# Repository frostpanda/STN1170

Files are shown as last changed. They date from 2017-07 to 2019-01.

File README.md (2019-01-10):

<h2><b>Prototype of common OBD diagnostic board </b></h2>

Device uses STN1170 chip in QFTP package, form ScanTool company and it is compatible with ELM327, based on information, which can be found in datasheet about this integrated circuit. 

Main assumption about this prototype to be a modular to lower the cost of the device, because only 3 samples can be acquired through ScanTool company, so prototype has two boards. One with STN1170 and necessary components and second one with transceivers, which are required for communication with proper protocols and OBD chip, but also contains wireless and wired communication. 

Wireless communication was planned RN4870 BLE module. But because of bad implementation (???) or module was broken I can not force him to work properly. In the end it lost MAC address and this is common for modules, based on IS187x Bluetooth LE ICs and the main reason for it was as Microchip support claim “Inappropriate module reset”, but I didn’t get answer for my question, when I asked about, how this module should be reset, to prevent such behavior in the future. Finally I decided for HM-13 module. Module is already implemented and I need to do more tweaking in revision 2 to push next revision. For now module is working on revision 1 prototype board.

Wired communication with PC uses CP2102N UART to Bridge ICs. His cost is lower than FTDI chips and has a lot possible ways to configure it, beginning from drivers, ending at ICs, but soldering it without hot air station is not easy task to do, but it can be done with some patience.

After success of 1st prototype (working!), second was made. On the 2nd prototype everything was moved to the one 2 layers PCB board, with dimension of 4cm x 6cm (I will try to make it even smaller!, but I am concern about EMC problem with it and this could require use 4 layer PCB). Some of components are on the bottom side of the board. 

Checked protocols:
- [x] High Speed CAN
- [x] Medium Speed CAN 
- [x] Single Wire CAN 
- [x] K-LINE
- [x] L-LINE
- [ ] VPW 
- [ ] PWM

Basic connection tested with:
- Fiat Punto MK2 1.2 8V (MultiEcuScan)
- Opel Vectra C 1.8 16V 122KM 
- Citroen DS4 
- Mazda 3 BK 1.6 105KM Z6 2008 (ForScan)

Gallery: https://imgur.com/a/UtiDV

Video: https://youtu.be/GFeOGx49xKc

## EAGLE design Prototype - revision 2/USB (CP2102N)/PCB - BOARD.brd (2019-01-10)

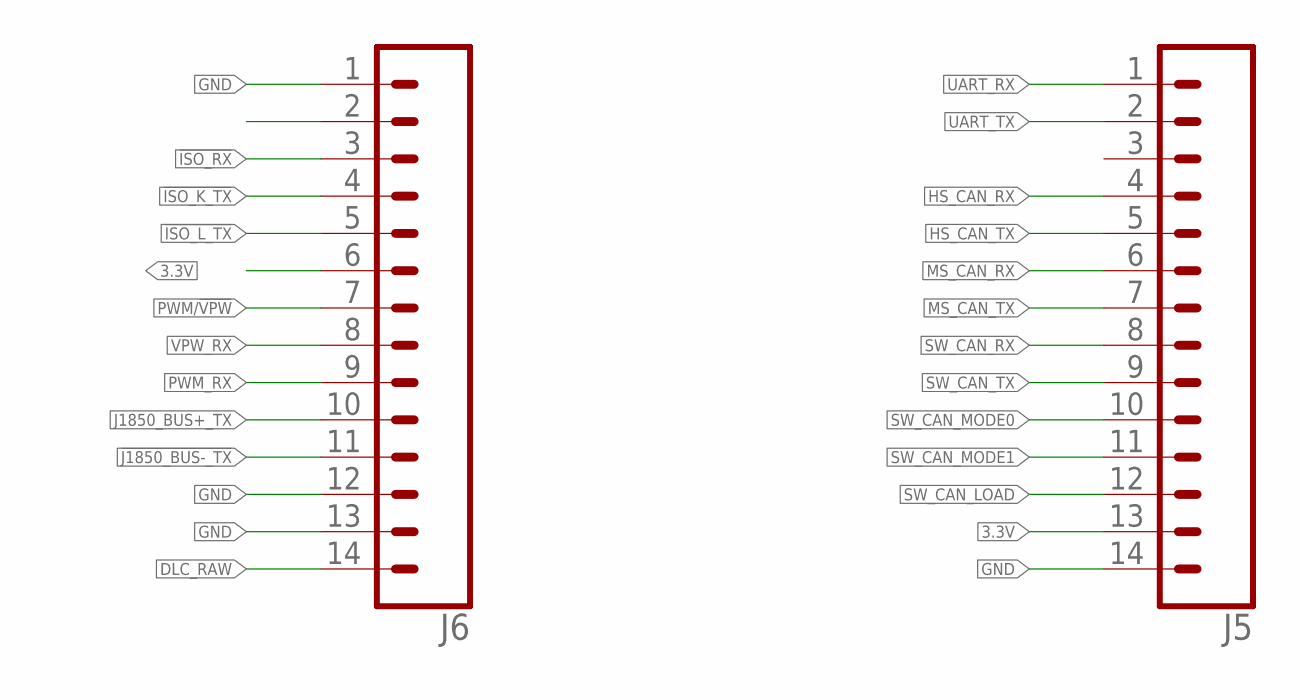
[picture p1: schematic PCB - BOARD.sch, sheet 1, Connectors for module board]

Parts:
J5, J6: CONN_14; 1X14

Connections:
3.3V: J5.13, J6.6; also elsewhere on the board
!ISO_K_TX: J6.4; also elsewhere on the board
!ISO_L_TX: J6.5; also elsewhere on the board
!ISO_RX: J6.3; also elsewhere on the board
!J1850_BUS-_TX: J6.11; also elsewhere on the board
DLC_RAW: J6.14; also elsewhere on the board
GND: J5.14, J6.1, J6.2, J6.12, J6.13; also elsewhere on the board
HS_CAN_RX: J5.4; also elsewhere on the board
HS_CAN_TX: J5.5; also elsewhere on the board
J1850_BUS+_TX: J6.10; also elsewhere on the board
MS_CAN_RX: J5.6; also elsewhere on the board
MS_CAN_TX: J5.7; also elsewhere on the board
PWM/!VPW: J6.7; also elsewhere on the board
PWM_RX: J6.9; also elsewhere on the board
SW_CAN_LOAD: J5.12; also elsewhere on the board
SW_CAN_MODE0: J5.10; also elsewhere on the board
SW_CAN_MODE1: J5.11; also elsewhere on the board
SW_CAN_RX: J5.8; also elsewhere on the board
SW_CAN_TX: J5.9; also elsewhere on the board
UART_RX: J5.1; also elsewhere on the board
UART_TX: J5.2; also elsewhere on the board
VPW_RX: J6.8; also elsewhere on the board

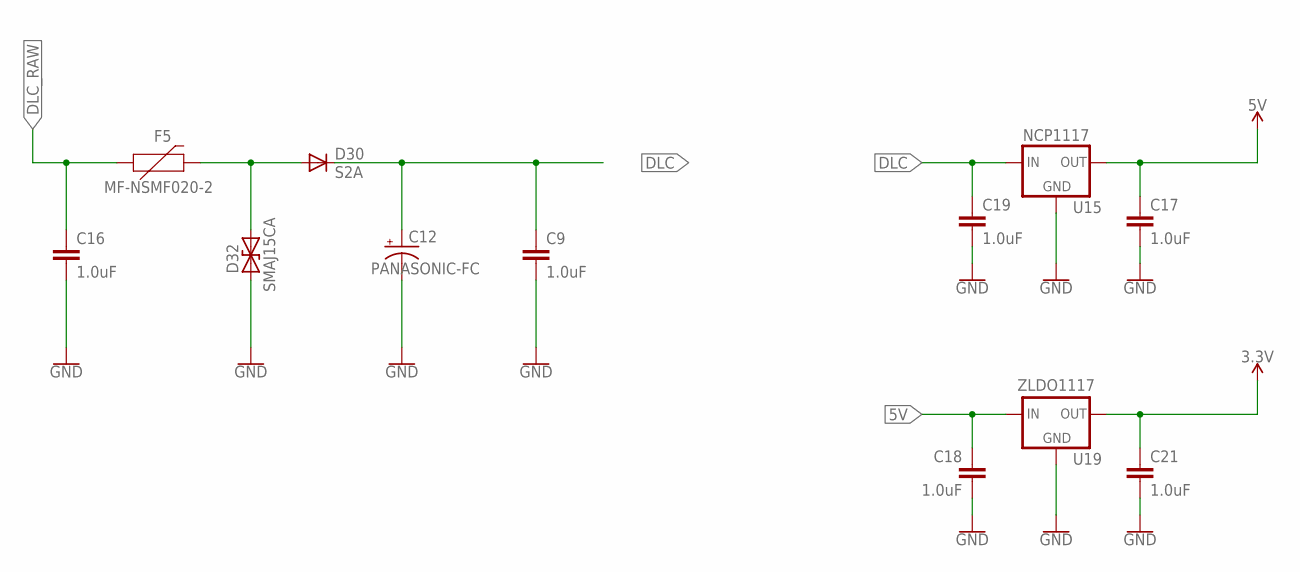
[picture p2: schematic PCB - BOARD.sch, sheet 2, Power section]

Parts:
C9, C16, C17, C18, C19, C21: 1.0uF; 0805
C12: PANASONIC-FC; 5X11
D30: S2A; DO214AA
D32: SMAJ15CA; DO214AC
F5: MF-NSMF020-2; 1206
U15: NCP1117; TO-252
U19: ZLDO1117; SOT223

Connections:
3.3V: C21.1, U19.2 (OUT), U19.4 (OUT); also elsewhere on the board
5V: C17.1, C18.1, U15.2 (OUT), U19.3 (IN); also elsewhere on the board
DLC: C9.1, C12.2 (+), C19.1, D30.C, U15.3 (IN); also elsewhere on the board
DLC_RAW: C16.1, F5.1; also elsewhere on the board
DLC_RAW2: D30.A, D32.C (2), F5.2
GND: C9.2, C12.1 (-), C16.2, C17.2, C18.2, C19.2, C21.2, D32.A (1), U15.1 (GND), U19.1 (GND); also elsewhere on the board

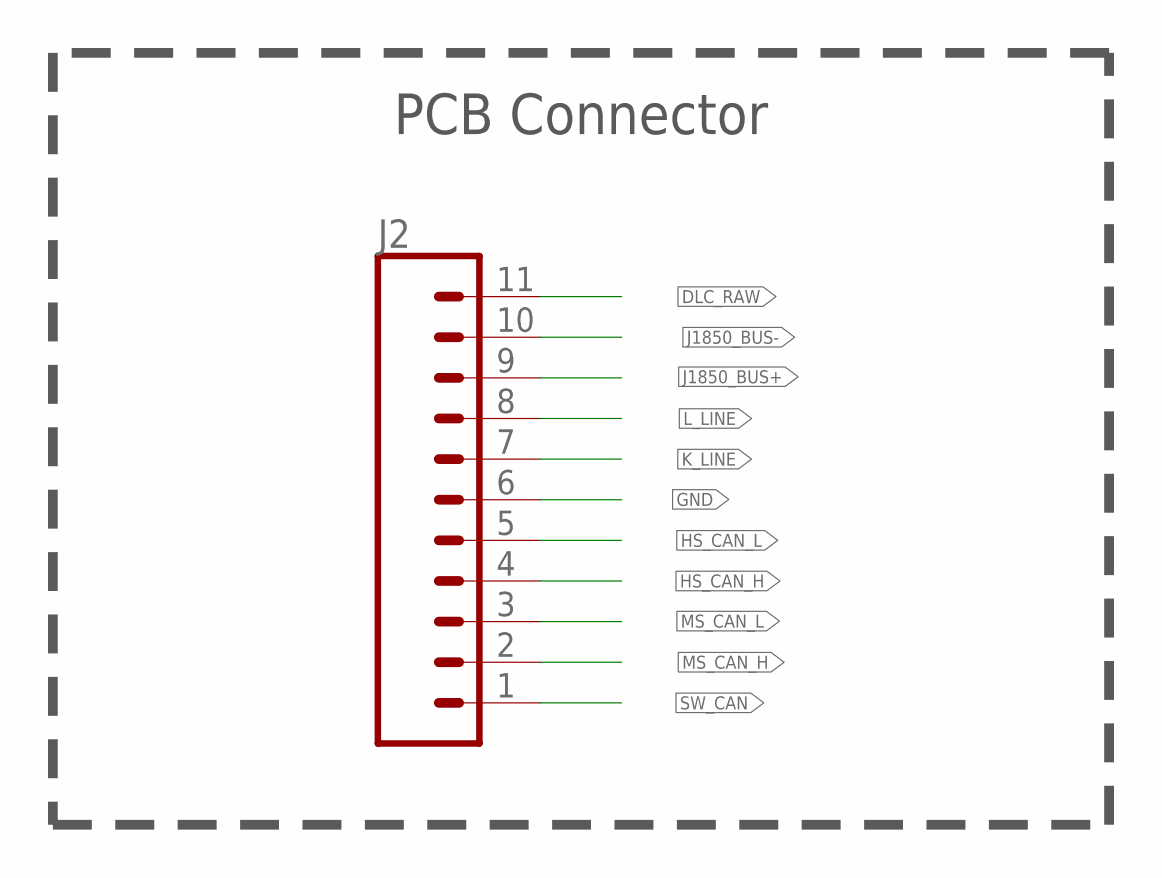
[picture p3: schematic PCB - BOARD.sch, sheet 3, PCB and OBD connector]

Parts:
J2: CONN_11; 1X11

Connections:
DLC_RAW: J2.11; also elsewhere on the board
GND: J2.6; also elsewhere on the board
HS_CAN_H: J2.4; also elsewhere on the board
HS_CAN_L: J2.5; also elsewhere on the board
J1850_BUS+: J2.9; also elsewhere on the board
J1850_BUS-: J2.10; also elsewhere on the board
K_LINE: J2.7; also elsewhere on the board
L_LINE: J2.8; also elsewhere on the board
MS_CAN_H: J2.2; also elsewhere on the board
MS_CAN_L: J2.3; also elsewhere on the board
SW_CAN: J2.1; also elsewhere on the board

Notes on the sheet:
PCB Connector

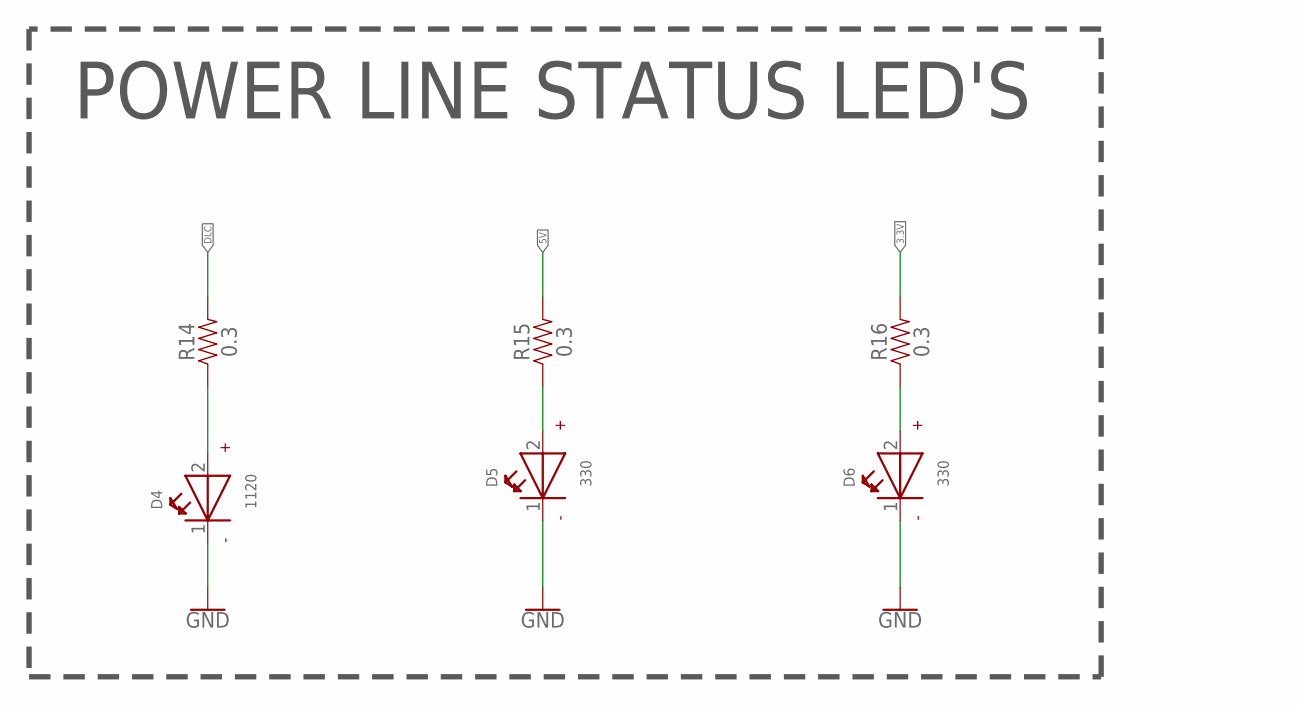
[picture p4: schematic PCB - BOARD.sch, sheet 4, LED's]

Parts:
D4: 1120; WL-SMCW_1206
D5, D6: 330; WL-SMCW_1206
R14, R15, R16: 0.3; 0805

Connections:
3.3V: R16.2; also elsewhere on the board
5V: R15.2; also elsewhere on the board
DLC: R14.2; also elsewhere on the board
GND: D4.1 (-), D5.1 (-), D6.1 (-); also elsewhere on the board
unnamed: D6.2 (+), R16.1
unnamed: D5.2 (+), R15.1
unnamed: D4.2 (+), R14.1

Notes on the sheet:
POWER LINE STATUS LED'S

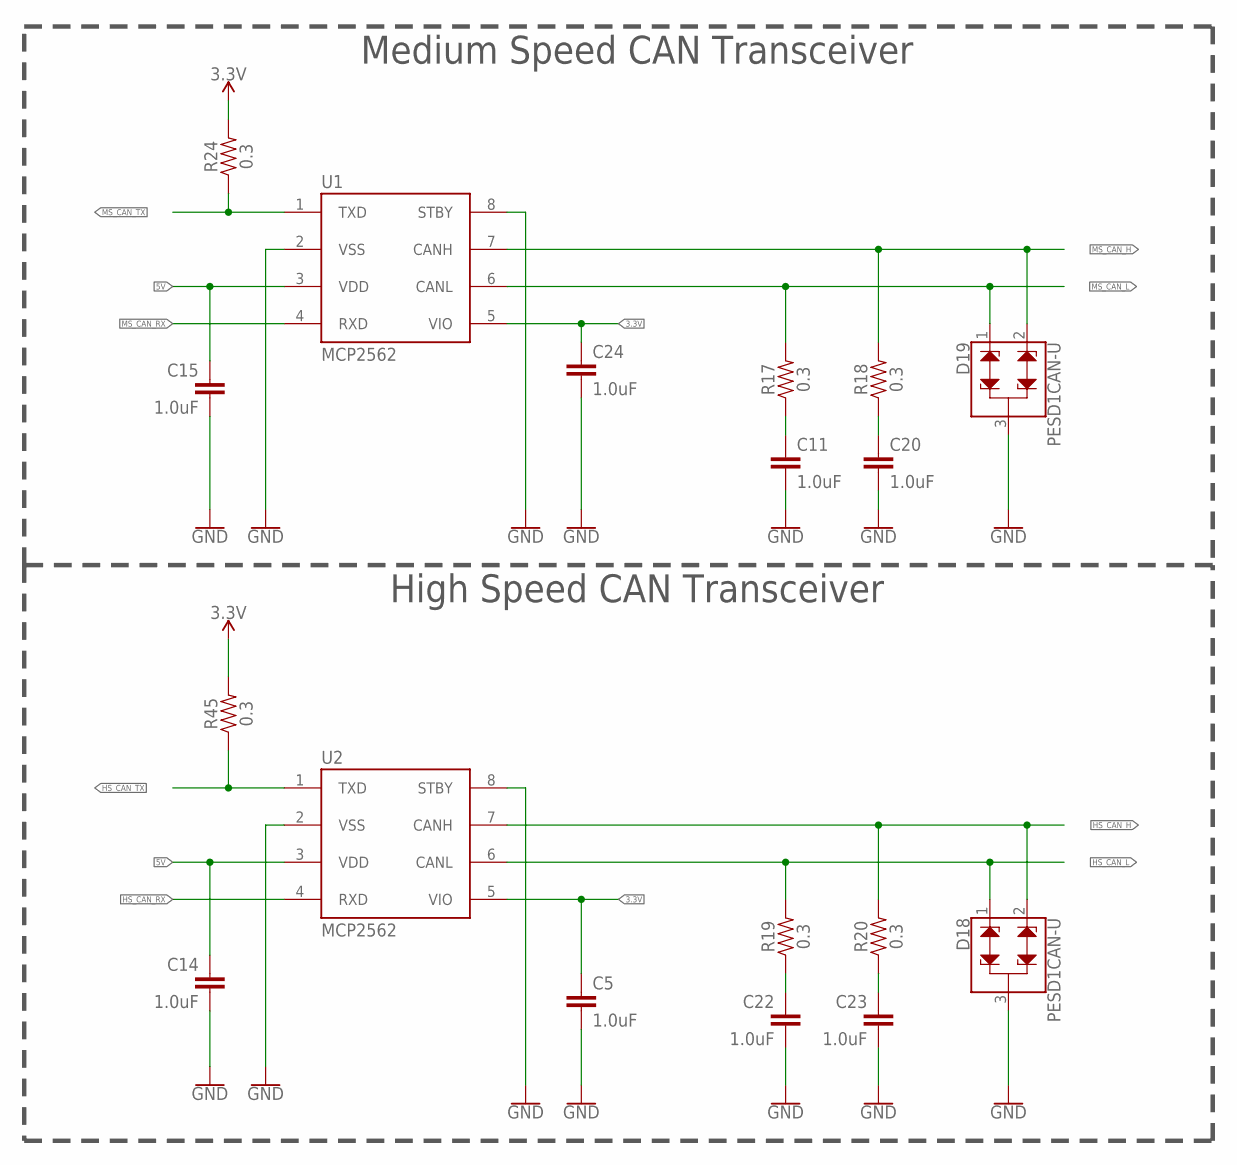
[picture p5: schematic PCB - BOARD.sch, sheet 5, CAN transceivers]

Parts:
C5, C11, C14, C15, C20, C22, C23, C24: 1.0uF; 0805
D18, D19: PESD1CAN-U; SOT323
R17, R18, R19, R20, R24, R45: 0.3; 0805
U1, U2: MCP2562; SOIC-8

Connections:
3.3V: C5.1, C24.1, R24.2, R45.2, U1.5 (VIO), U2.5 (VIO); also elsewhere on the board
5V: C14.1, C15.1, U1.3 (VDD), U2.3 (VDD); also elsewhere on the board
GND: C5.2, C11.2, C14.2, C15.2, C20.2, C22.2, C23.2, C24.2, D18.3, D19.3, U1.2 (VSS), U1.8 (STBY), U2.2 (VSS), U2.8 (STBY); also elsewhere on the board
HS_CAN_H: D18.2, R20.2, U2.7 (CANH); also elsewhere on the board
HS_CAN_L: D18.1, R19.2, U2.6 (CANL); also elsewhere on the board
HS_CAN_RX: U2.4 (RXD); also elsewhere on the board
HS_CAN_TX: R45.1, U2.1 (TXD); also elsewhere on the board
MS_CAN_H: D19.2, R18.2, U1.7 (CANH); also elsewhere on the board
MS_CAN_L: D19.1, R17.2, U1.6 (CANL); also elsewhere on the board
MS_CAN_RX: U1.4 (RXD); also elsewhere on the board
MS_CAN_TX: R24.1, U1.1 (TXD); also elsewhere on the board
unnamed: C11.1, R17.1
unnamed: C20.1, R18.1
unnamed: C22.1, R19.1
unnamed: C23.1, R20.1

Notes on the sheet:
Medium Speed CAN Transceiver
High Speed CAN Transceiver

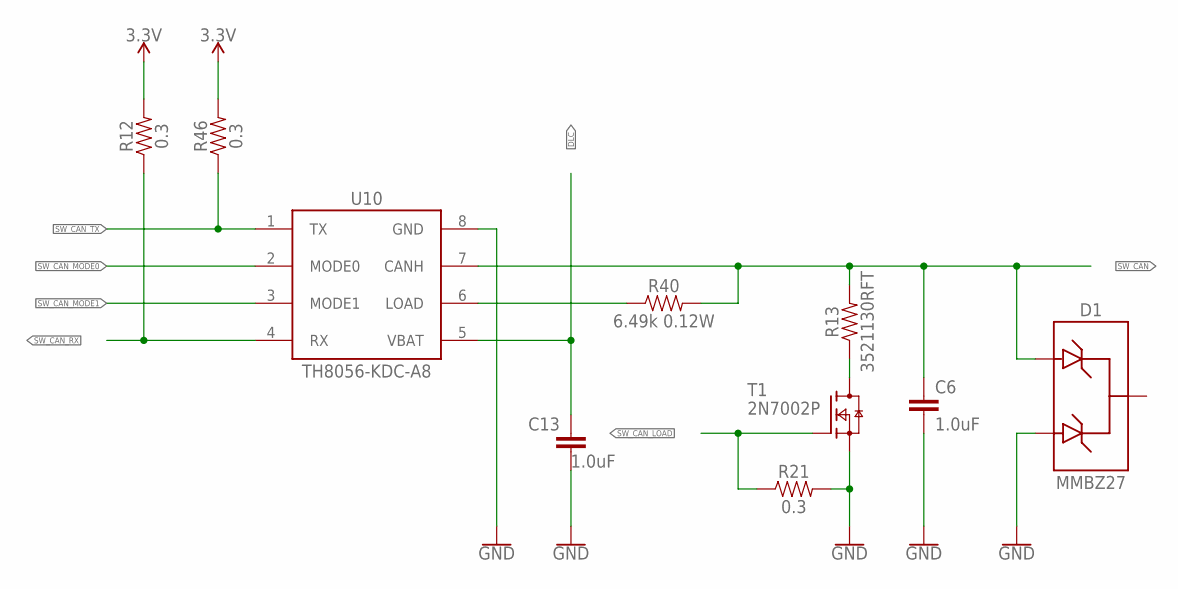
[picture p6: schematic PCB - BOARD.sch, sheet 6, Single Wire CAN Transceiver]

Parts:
C6, C13: 1.0uF; 0805
D1: MMBZ27; SOT23-3
R12, R21, R46: 0.3; 0805
R13: 3521130RFT; 3521
R40: 6.49k 0.12W; 1206
T1: 2N7002P; SOT23
U10: TH8056-KDC-A8; SOIC-8

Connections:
3.3V: R12.2, R46.2; also elsewhere on the board
DLC: C13.1, U10.5 (VBAT); also elsewhere on the board
GND: C6.2, C13.2, D1.2 (A2), R21.2, T1.2 (S), U10.8 (GND); also elsewhere on the board
LOAD: R40.1, U10.6 (LOAD)
unnamed: R13.1, T1.3 (D)
SW_CAN: C6.1, D1.1 (A1), R13.2, R40.2, U10.7 (CANH); also elsewhere on the board
SW_CAN_LOAD: R21.1, T1.1 (G); also elsewhere on the board
SW_CAN_MODE0: U10.2 (MODE0); also elsewhere on the board
SW_CAN_MODE1: U10.3 (MODE1); also elsewhere on the board
SW_CAN_RX: R12.1, U10.4 (RX); also elsewhere on the board
SW_CAN_TX: R46.1, U10.1 (TX); also elsewhere on the board

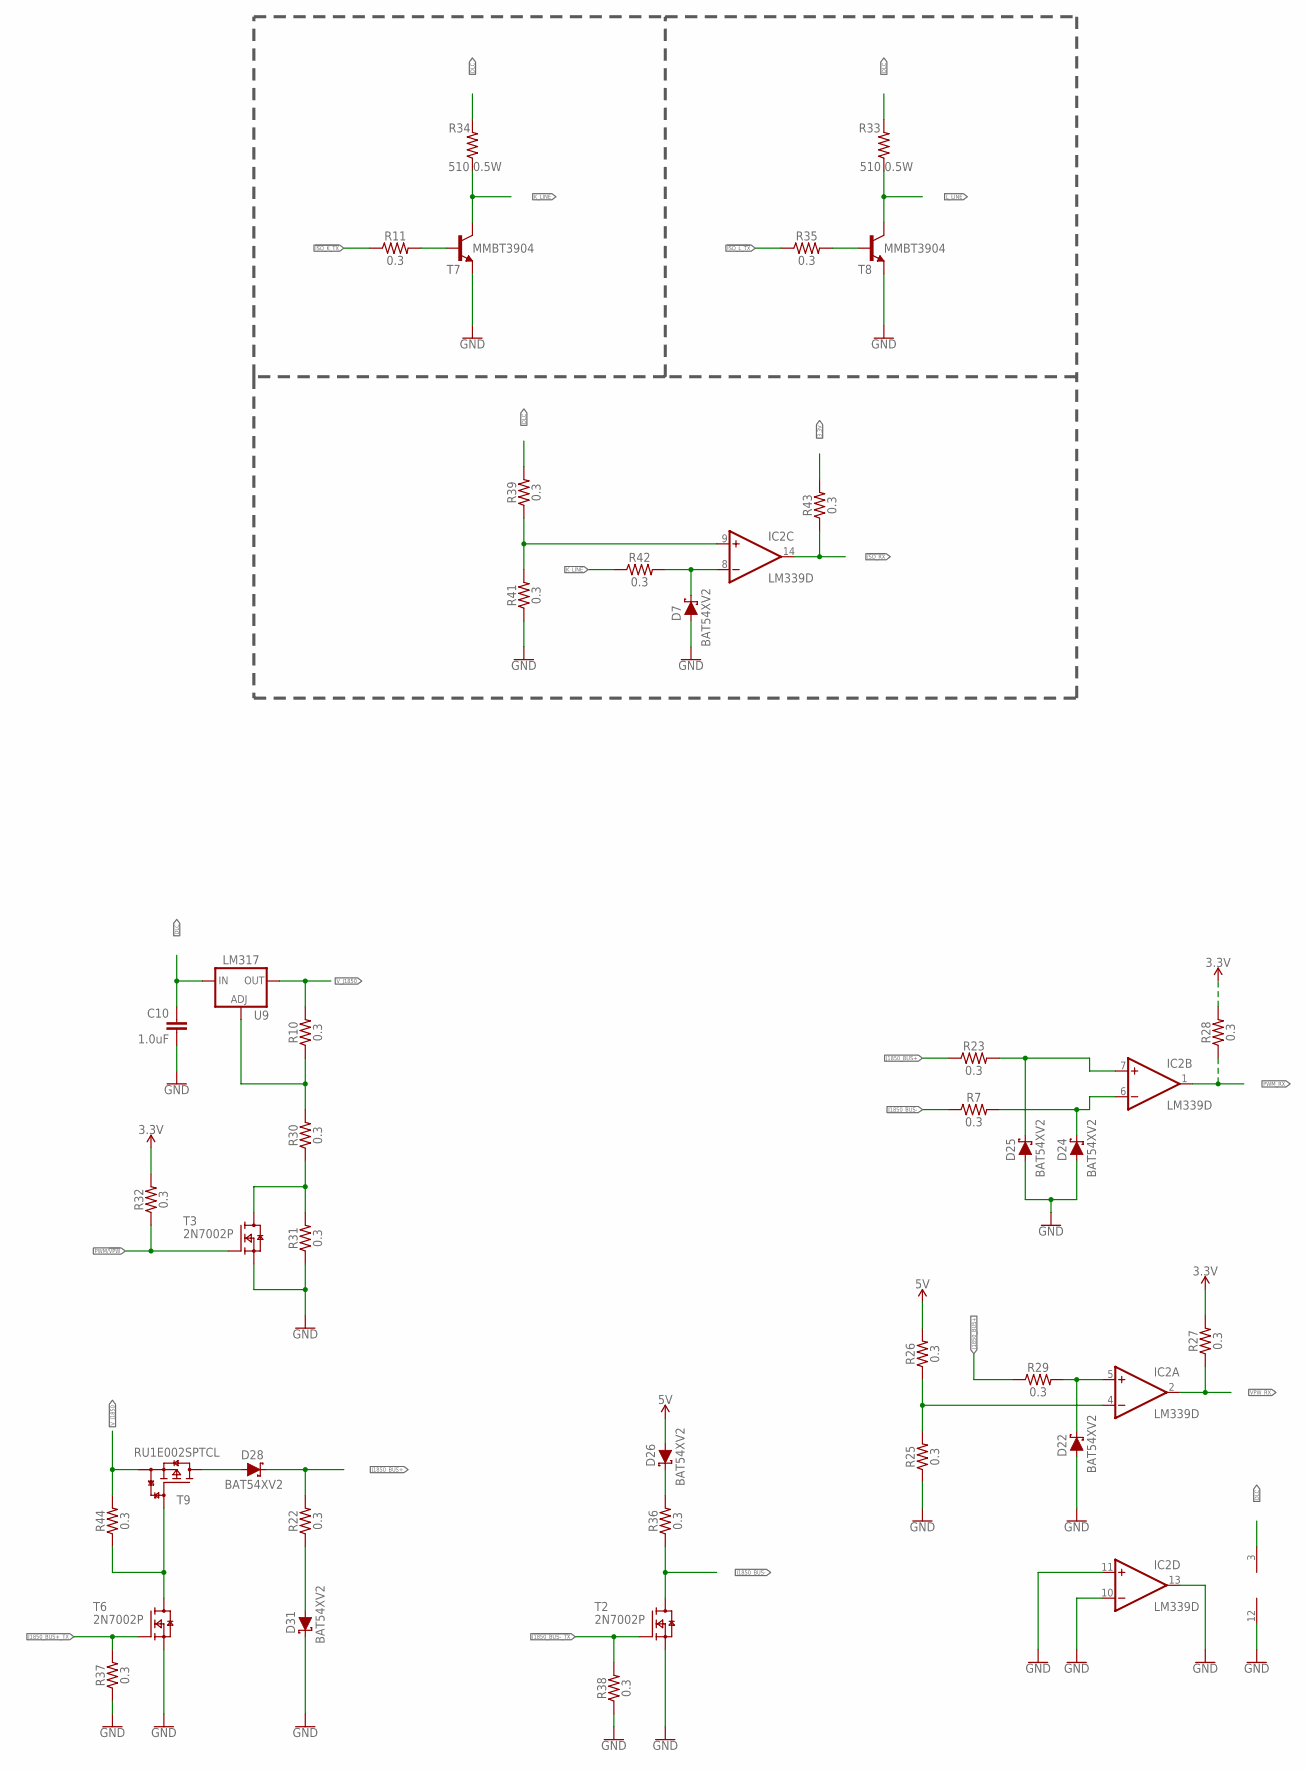
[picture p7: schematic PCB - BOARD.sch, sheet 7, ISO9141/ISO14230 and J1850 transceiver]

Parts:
C10: 1.0uF; 0805
D7, D22, D24, D25, D26, D28, D31: BAT54XV2; SOD-523F
IC2: LM339D; SO14
R7, R10, R11, R22, R23, R25, R26, R27, R28, R29, R30, R31, R32, R35, R36, R37, R38, R39, R41, R42, R43, R44: 0.3; 0805
R33, R34: 510 0.5W; 1210
T2, T3, T6: 2N7002P; SOT23
T7, T8: MMBT3904; SOT23-BEC
T9: RU1E002SPTCL; SOT323
U9: LM317; SOT223

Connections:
3.3V: R27.2, R28.2, R32.2, R43.2; also elsewhere on the board
5V: D26.A, R26.2; also elsewhere on the board
!ISO_K_TX: R11.1; also elsewhere on the board
!ISO_L_TX: R35.1; also elsewhere on the board
!ISO_RX: IC2.14 (OUT), R43.1; also elsewhere on the board
!J1850_BUS-_TX: R38.2, T2.1 (G); also elsewhere on the board
ADJ: R10.1, R30.2, U9.1 (ADJ)
COMPARATOR+: D22.C, IC2.5 (+IN), R29.2
COMPARATOR-: IC2.4 (-IN), R25.2, R26.1
DLC: C10.1, IC2.3 (V+), R33.2, R34.2, R39.2, U9.3 (IN); also elsewhere on the board
GND: C10.2, D7.A, D22.A, D24.A, D25.A, D31.C, IC2.10 (-IN), IC2.11 (+IN), IC2.12 (GND), IC2.13 (OUT), R25.1, R31.1, R37.1, R38.1, R41.1, T2.2 (S), T3.2 (S), T6.2 (S), T7.E, T8.E; also elsewhere on the board
J1850_BUS+: D25.C, D28.C, IC2.7 (+IN), R22.2, R23.1, R23.2, R29.1; also elsewhere on the board
J1850_BUS+_TX: R37.2, T6.1 (G); also elsewhere on the board
J1850_BUS-: D24.C, IC2.6 (-IN), R7.1, R7.2, R36.1, T2.3 (D); also elsewhere on the board
K-LINE: D7.C, IC2.8 (-IN), R42.2
K_LINE: R34.1, R42.1, T7.C; also elsewhere on the board
L_LINE: R33.1, T8.C; also elsewhere on the board
unnamed: R44.1, T6.3 (D), T9.1 (G)
unnamed: D26.C, R36.2
unnamed: IC2.9 (+IN), R39.1, R41.2
unnamed: D28.A, T9.3 (D)
unnamed: D31.A, R22.1
unnamed: R35.2, T8.B
unnamed: R11.2, T7.B
unnamed: R30.1, R31.2, T3.3 (D)
PWM/!VPW: R32.1, T3.1 (G); also elsewhere on the board
PWM_RX: IC2.1 (OUT), R28.1; also elsewhere on the board
VPW_RX: IC2.2 (OUT), R27.1; also elsewhere on the board
V_J1850: R10.2, R44.2, T9.2 (S), U9.2 (OUT), U9.4 (OUT)

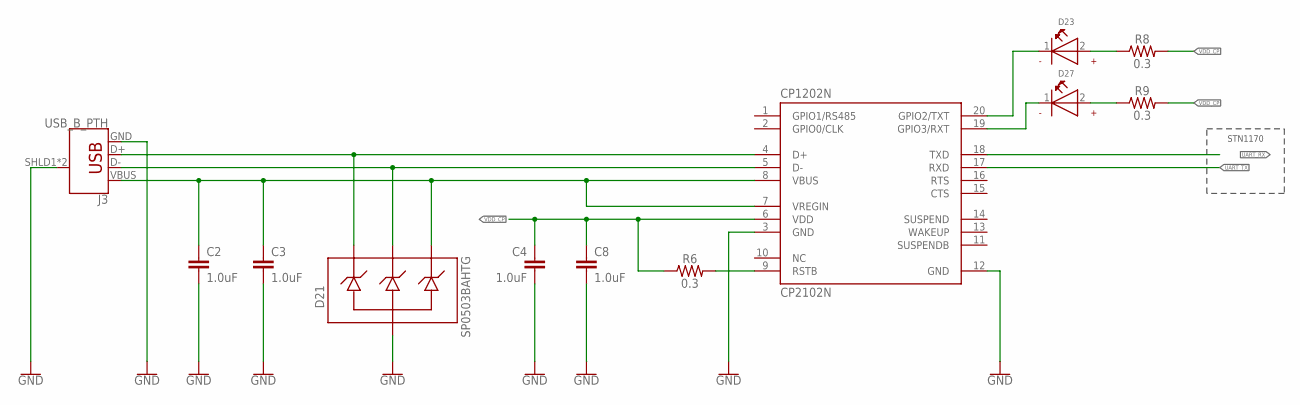
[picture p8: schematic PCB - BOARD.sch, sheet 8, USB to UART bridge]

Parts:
C2, C3, C4, C8: 1.0uF; 0805
CP1202N: CP2102N; QFN20
D21: SP0503BAHTG; SOT143-4
D23, D27: WL-SMCW-150120BS75000-B; WL-SMCW_1206
J3: USB_B_PTH; USB-B-PTH
R6, R8, R9: 0.3; 0805

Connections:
D+: CP1202N.4 (D+), D21.4, J3.D+
D-: CP1202N.5 (D-), D21.3, J3.D-
GND: C2.2, C3.2, C4.2, C8.2, CP1202N.3 (GND), CP1202N.12 (GND), D21.1, J3.GND, J3.SHLD1 (SHIELD), J3.SHLD2 (SHIELD); also elsewhere on the board
unnamed: CP1202N.9 (RSTB), R6.2
unnamed: CP1202N.20 (GPIO2/TXT), D23.1 (-)
unnamed: CP1202N.19 (GPIO3/RXT), D27.1 (-)
unnamed: D23.2 (+), R8.1
unnamed: D27.2 (+), R9.1
UART_RX: CP1202N.18 (TXD); also elsewhere on the board
UART_TX: CP1202N.17 (RXD); also elsewhere on the board
VBUS: C2.1, C3.1, CP1202N.7 (VREGIN), CP1202N.8 (VBUS), D21.2, J3.VBUS
VDD_CP: C4.1, C8.1, CP1202N.6 (VDD), R6.1, R8.2, R9.2

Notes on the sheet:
STN1170

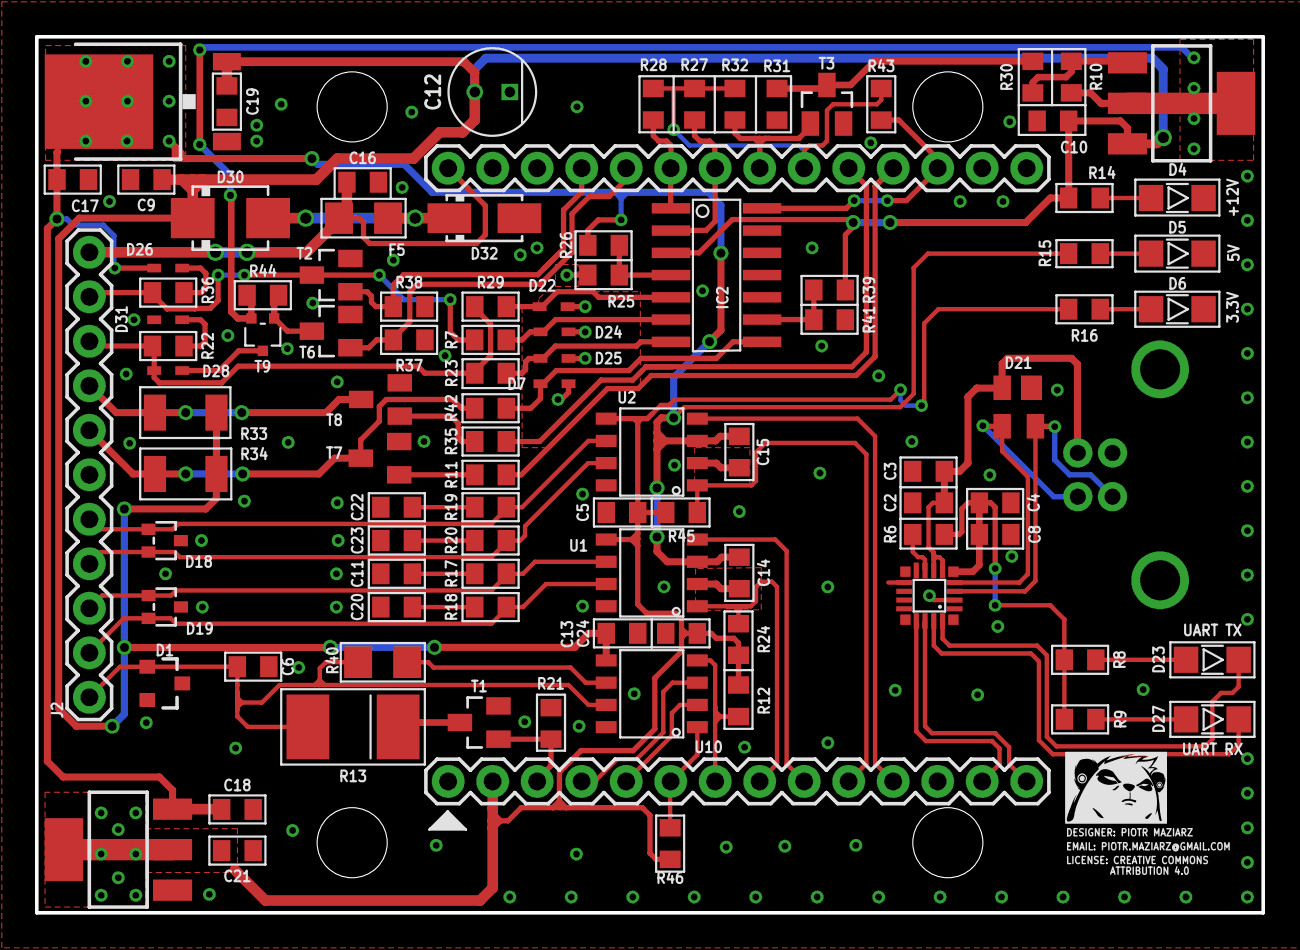
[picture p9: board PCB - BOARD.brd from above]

Board: 2 copper layers, 70.0 x 50.0 mm, 103 parts (1 on the bottom side), 65 nets.

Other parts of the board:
U$1, U$2: LOGO2

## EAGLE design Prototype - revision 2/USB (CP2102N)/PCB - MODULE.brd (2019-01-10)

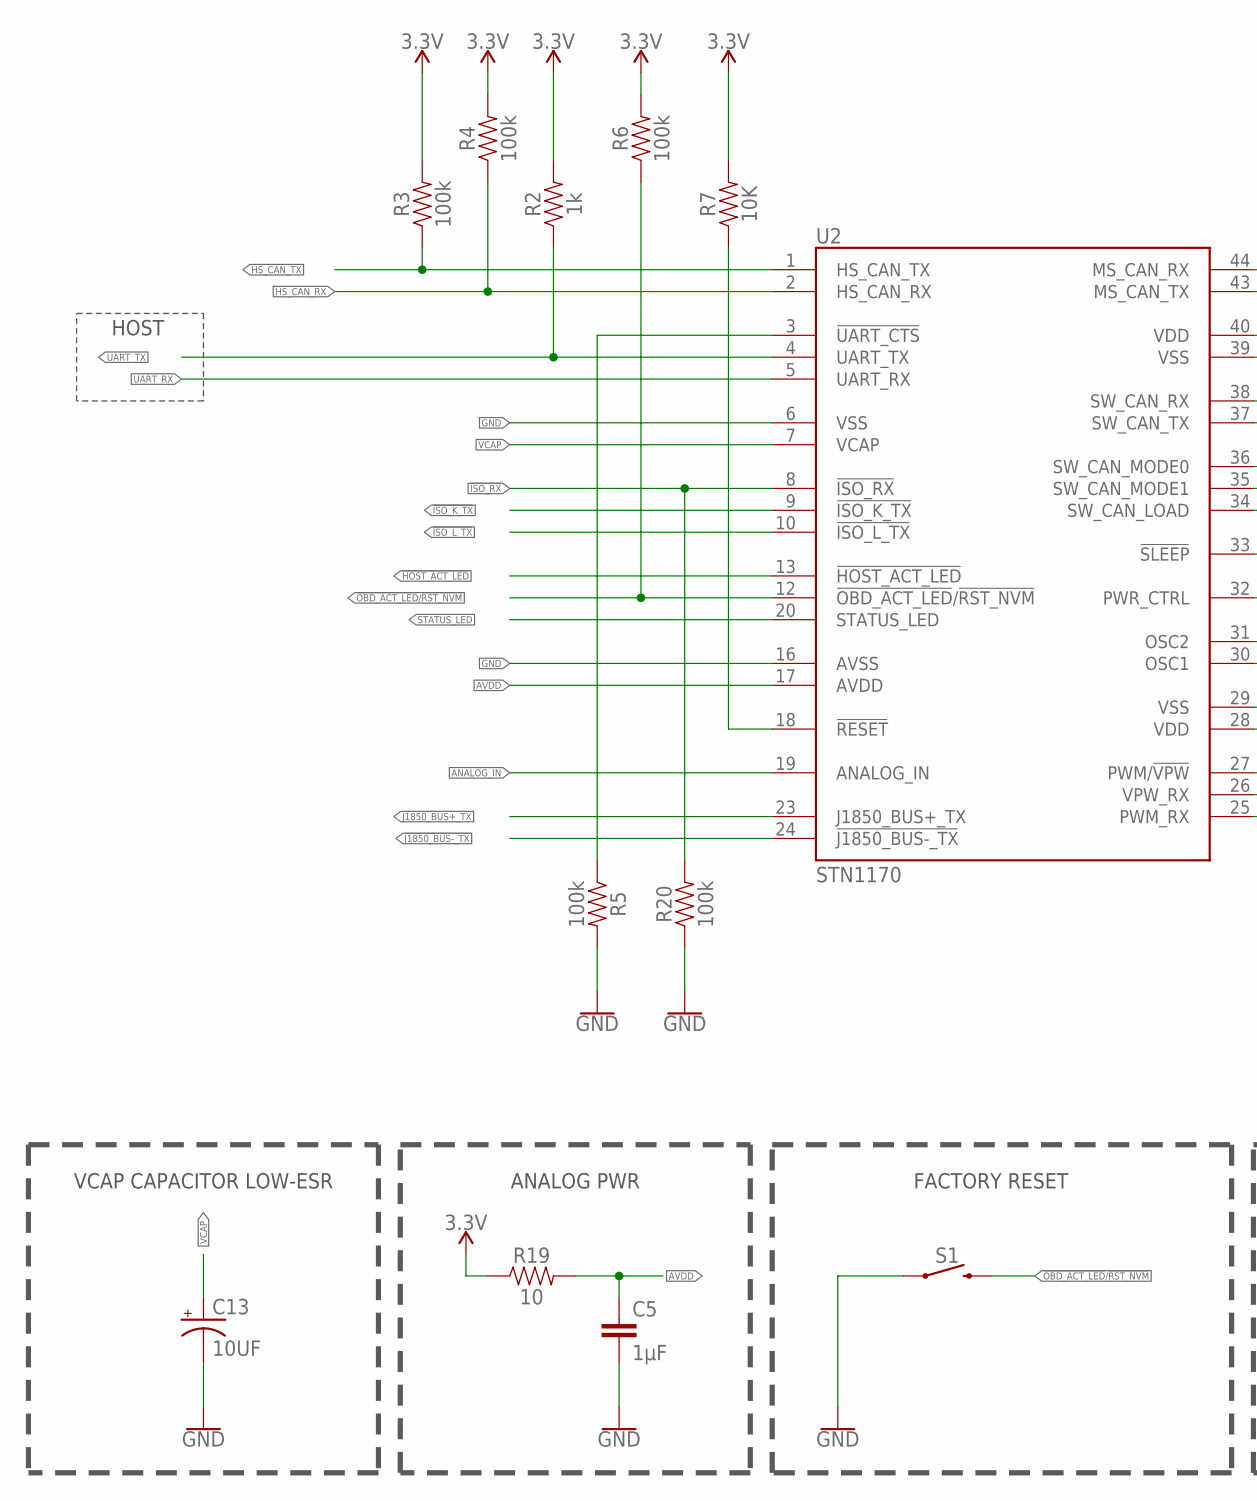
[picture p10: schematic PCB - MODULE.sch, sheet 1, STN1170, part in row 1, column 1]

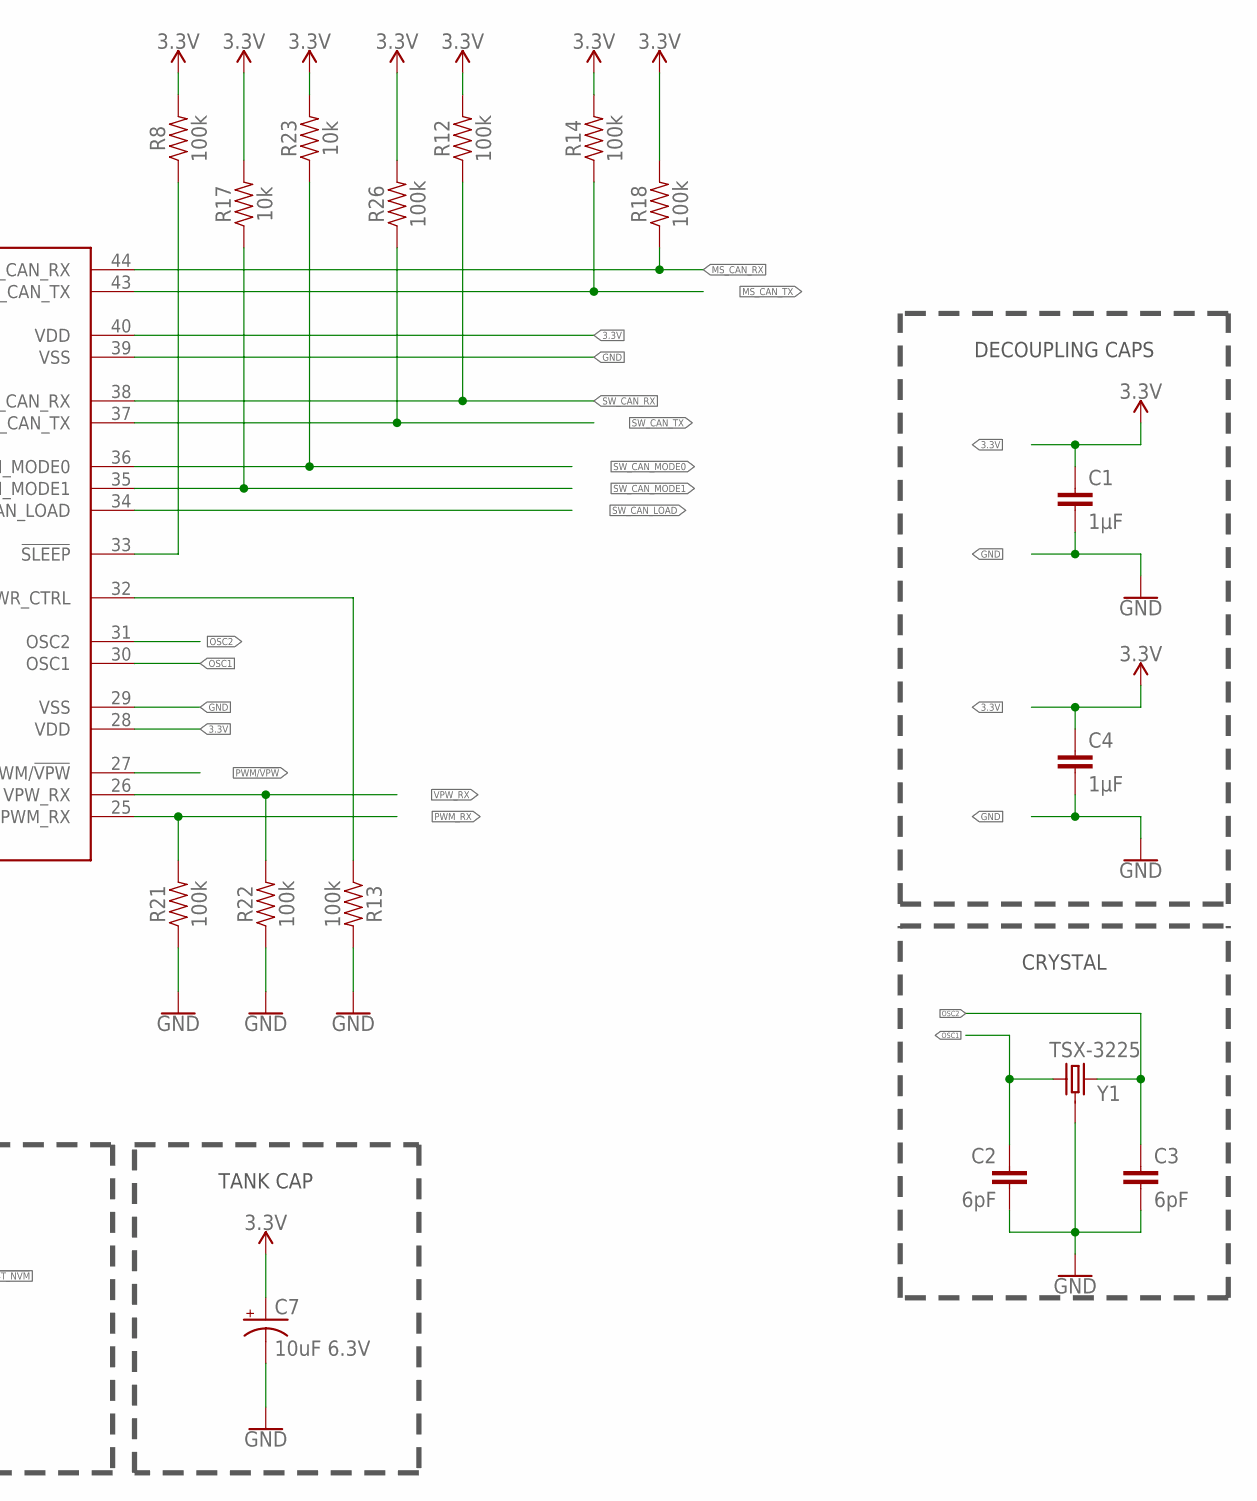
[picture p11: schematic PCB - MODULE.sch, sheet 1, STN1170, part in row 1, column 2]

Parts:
C1, C4, C5: 1µF; 0805
C2, C3: 6pF; 0805
C7: 10uF 6.3V; EIA3216
C13: 10UF; 1206
R2: 1k; 0805
R3, R4, R5, R6, R8, R12, R13, R14, R18, R20, R21, R22, R26: 100k; 0805
R7: 10K; 0805
R17, R23: 10k; 0805
R19: 10; 0805
S1: B3U; B3U-WO-GT-WO-B
U2: STN1170; TQFP44
Y1: TSX-3225; TSX-3225-SOLDERING-IRON

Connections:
3.3V: C1.1, C4.1, C7.+, R2.2, R3.2, R4.2, R6.2, R7.2, R8.2, R12.2, R14.2, R17.2, R18.2, R19.1, R23.2, R26.2, U2.28 (VDD), U2.40 (VDD); also elsewhere on the board
!HOST_ACT_LED: U2.13 (!HOST_ACT_LED); also elsewhere on the board
!ISO_K_TX: U2.9 (!ISO_K_TX); also elsewhere on the board
!ISO_L_TX: U2.10 (!ISO_L_TX); also elsewhere on the board
!ISO_RX: R20.2, U2.8 (!ISO_RX); also elsewhere on the board
!J1850_BUS-_TX: U2.24 (!J1850_BUS-_TX); also elsewhere on the board
!OBD_ACT_LED!/!RST_NVM: R6.1, S1.2, U2.12 (!OBD_ACT_LED!/!RST_NVM); also elsewhere on the board
!RESET: R7.1, U2.18 (!RESET)
!SLEEP: R8.1, U2.33 (!SLEEP)
!UART_CTS: R5.1, U2.3 (!UART_CTS)
ANALOG_IN: U2.19 (ANALOG_IN); also elsewhere on the board
AVDD: C5.1, R19.2, U2.17 (AVDD)
GND: C1.2, C2.2, C3.2, C4.2, C5.2, C7.-, C13.2 (-), R5.2, R13.2, R20.1, R21.1, R22.1, S1.1, U2.6 (VSS), U2.16 (AVSS), U2.29 (VSS), U2.39 (VSS), Y1.2 (3), Y1.4 (3); also elsewhere on the board
HS_CAN_RX: R4.1, U2.2 (HS_CAN_RX); also elsewhere on the board
HS_CAN_TX: R3.1, U2.1 (HS_CAN_TX); also elsewhere on the board
J1850_BUS+_TX: U2.23 (J1850_BUS+_TX); also elsewhere on the board
MS_CAN_RX: R18.1, U2.44 (MS_CAN_RX); also elsewhere on the board
MS_CAN_TX: R14.1, U2.43 (MS_CAN_TX); also elsewhere on the board
OSC1: C2.1, U2.30 (OSC1), Y1.1
OSC2: C3.1, U2.31 (OSC2), Y1.3 (2)
PWM/!VPW: U2.27 (PWM/!VPW!); also elsewhere on the board
PWM_RX: R21.2, U2.25 (PWM_RX); also elsewhere on the board
PWR_CTRL: R13.1, U2.32 (PWR_CTRL)
STATUS_LED: U2.20 (STATUS_LED); also elsewhere on the board
SW_CAN_LOAD: U2.34 (SW_CAN_LOAD); also elsewhere on the board
SW_CAN_MODE0: R23.1, U2.36 (SW_CAN_MODE0); also elsewhere on the board
SW_CAN_MODE1: R17.1, U2.35 (SW_CAN_MODE1); also elsewhere on the board
SW_CAN_RX: R12.1, U2.38 (SW_CAN_RX); also elsewhere on the board
SW_CAN_TX: R26.1, U2.37 (SW_CAN_TX); also elsewhere on the board
UART_RX: U2.5 (UART_RX); also elsewhere on the board
UART_TX: R2.1, U2.4 (UART_TX); also elsewhere on the board
VCAP: C13.1 (+), U2.7 (VCAP)
VPW_RX: R22.2, U2.26 (VPW_RX); also elsewhere on the board

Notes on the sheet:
HOST
ANALOG PWR
CRYSTAL
VCAP CAPACITOR LOW-ESR
DECOUPLING CAPS
FACTORY RESET
TANK CAP

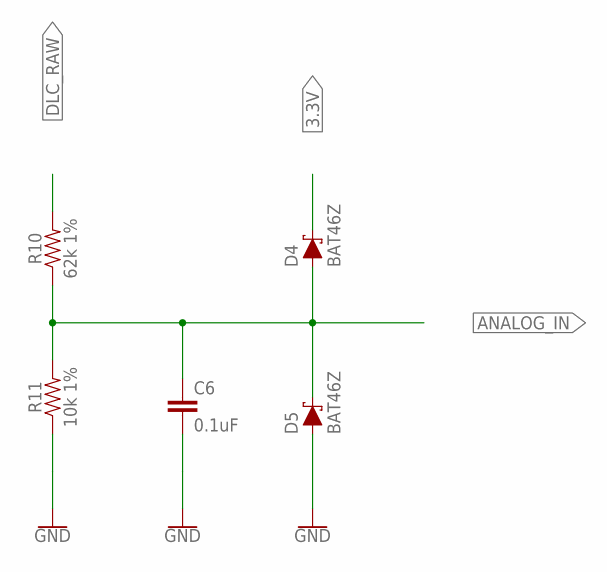
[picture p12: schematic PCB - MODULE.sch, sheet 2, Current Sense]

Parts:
C6: 0.1uF; 0805
D4, D5: BAT46Z; SOD-123
R10: 62k 1%; 0805
R11: 10k 1%; 0805

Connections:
3.3V: D4.C; also elsewhere on the board
ANALOG_IN: C6.1, D4.A, D5.C, R10.1, R11.2; also elsewhere on the board
DLC_RAW: R10.2; also elsewhere on the board
GND: C6.2, D5.A, R11.1; also elsewhere on the board


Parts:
D1: STATUS-LED; WL-SMCW_1206
D2: UART-LED; WL-SMCW_1206
D3: OBD-LED; WL-SMCW_1206
R1, R15, R16: 330; 0805

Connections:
3.3V: D2.2 (+), D3.2 (+); also elsewhere on the board
!HOST_ACT_LED: R15.1; also elsewhere on the board
!OBD_ACT_LED!/!RST_NVM: R16.1; also elsewhere on the board
GND: D1.1 (-); also elsewhere on the board
unnamed: D1.2 (+), R1.2
unnamed: D3.1 (-), R16.2
unnamed: D2.1 (-), R15.2
STATUS_LED: R1.1; also elsewhere on the board

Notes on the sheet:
OBD STATUS LED'S

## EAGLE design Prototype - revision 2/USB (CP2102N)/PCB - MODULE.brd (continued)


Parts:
J1, J2: CONN_14; 1X14

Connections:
3.3V: J1.13, J2.6; also elsewhere on the board
!ISO_K_TX: J2.4; also elsewhere on the board
!ISO_L_TX: J2.5; also elsewhere on the board
!ISO_RX: J2.3; also elsewhere on the board
!J1850_BUS-_TX: J2.11; also elsewhere on the board
DLC_RAW: J2.14; also elsewhere on the board
GND: J1.14, J2.1, J2.13; also elsewhere on the board
HS_CAN_RX: J1.4; also elsewhere on the board
HS_CAN_TX: J1.5; also elsewhere on the board
J1850_BUS+_TX: J2.10; also elsewhere on the board
MS_CAN_RX: J1.6; also elsewhere on the board
MS_CAN_TX: J1.7; also elsewhere on the board
PWM/!VPW: J2.7; also elsewhere on the board
PWM_RX: J2.9; also elsewhere on the board
SW_CAN_LOAD: J1.12; also elsewhere on the board
SW_CAN_MODE0: J1.10; also elsewhere on the board
SW_CAN_MODE1: J1.11; also elsewhere on the board
SW_CAN_RX: J1.8; also elsewhere on the board
SW_CAN_TX: J1.9; also elsewhere on the board
UART_RX: J1.1; also elsewhere on the board
UART_TX: J1.2; also elsewhere on the board
VPW_RX: J2.8; also elsewhere on the board


Board: 2 copper layers, 35.8 x 37.9 mm, 43 parts (1 on the bottom side), 37 nets.

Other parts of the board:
U$1, U$2: LOGO2

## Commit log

2017-06-21 STN1170 prototype (#1)
    STN1170 prototype
    [PCB - BOARD.brd, PCB - BOARD.sch, PCB - MODULE.brd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]
2017-06-23 Improvements in PCB layout
    1. Changed old TSX-3225 to version with bigger pads (now soldering should be easier, especially using soldering iron).
    2. Changed layout of a guard ring and crystal with capacitors to match new TSX-3225 pads. Capacitors C2 and C3 now are placed wider than before. This will help with soldering, without worry about STN or crystal pins. Also TSX-3225 can be used with smaller pads, wihtout need to rework guard ring, but this require to do new placement of the crystal and to make new traces for crystal and caps. Guard ring contains only 3 polygons, comparing to old implementation.
    3. Changed position of R8 and R13 resistors and traces for them. This modification remov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
    [PCB - MODULE.brd, PCB - MODULE.sch]
2017-06-23 Fix regulators name
    - Changed LDO names to the original value of the element. Choosed LDO has different pinout, compared to 7805 and LM317 LDO.
    - Future commts will bring back NCP1117 LDO for 5V power line and ZLODO1117-3.3 for 3.3V power line
    [PCB - BOARD.brd, PCB - BOARD.sch]
2017-06-24 Fixes/improvements/replace
    CP2102N:
    -SCHEMATIC:
    1. Changed connection to GND, instead of GND_CP. This will be explained in BOARD section.
    2. Rearranged status LED's and resistor for them and now they are powered by CP2102N integrated LDO instead of 3.3V power line.
    3. Minor improvements in CP2102N sheet schematic readability.
    BOARD:
    1. Deleted top and bottom polygon with different voltage reference. Using 12V+ power and powering bridge from USB in the same time and try to communicate with STN1170 causes instability in UART data transfer. Voltage reference need to be common for whole board.
    2. Changed D-, D+ and VBUS traces route to be more optimal.
    5V regulator:
    -Schematic:
    1. Changed MC78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
    [PCB - BOARD.brd, PCB - BOARD.sch]
2017-06-25 3.3V regulator/optimize filter section/others
    Schematic:
    1. Changed MCP1703 LDO regulator to ZLDO1117 regulator.
    2. Changed value of C18 and C19 to 4.7uF.
    Board:
    1. Rearranged regulator position, due to a different pinout.
    2. Changed traces route for DLC going into ZLDO1117 input and output due to different pinout and elements placement.
    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
    [PCB - BOARD.brd, PCB - BOARD.sch]
2017-06-27 Changes/updates
    1. Changed connection between the CP2102N LED's and IC.
    2. Another minor improvements in CP2102N sheet schematic readability.
    1. Relocated CP2102N chip inside the board.
    2. Rearranged C1, C2, C3, C4, D2, J3, R3 components because of new position of the CP2102N.
    3. D8 and D9 LED's are now powered by CP2102N.
    4. Changed polarity of the D8 and D9. Now they are controlled using GND, instead of 3.3V.
    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
    [PCB - BOARD.brd, PCB - BOARD.sch]
2017-06-27 Hotfix/changes/optimization
    1. Updated NCP1117 device in schematic and board files. Now it is 100% correct (LOL).
    2. Reroute traces because of fixed pinout of the NCP1117 (LOL).
    3. Some minor improvements in component placement, near LM339 comparator for easier soldering (R25, R26, R39, R41, vias). Easier
    4. Added to connector J6 3.3V power line on pin 6 for R27, R28, and R32 resistors. This allowed to reduce traces on the bottom side of the board.
    5. Changed trace route of K-LINE signal, from T7 to R47 element (matter of esthetics).
    6. Removed bridge from the bottom side of the board, connecting DLC_RAW2 between F5, D32 and D30. The trace was moved to the top layer.
    7. Optimized length of H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
    [PCB - BOARD.brd, PCB - BOARD.sch]
2017-06-27 Add
    Added to the J2 connector on pin 6 3.3V output for resistors, which can be found on daughter board.
    [PCB - MODULE.brd, PCB - MODULE.sch]
2017-06-28 Improvements
    1. Rearranged position of R7, R23, R29, D7, D22, D24 and D25 for easier soldering.
    2. Reroute signal traces (COMPARATOR+, J1850_BUS-, J1850_BUS+) because of new placement of elements, which was moved. Now this look a little cleaner than before.
    3. K-LLINE signal trace was moved by few millimeters from !ISO_L_TX.
    4. Minor improvements in component placement, near LM339 comparator for easier soldering (R39, R41, vias).
    TO DO:
    1. Because of difficulties to get TJA1048 in my country and NXP do not have this IC in sample program anymore, this part will be changed to 2 independent CAN transceivers in near future.
    2. Maybe replace J2 connector with fancier one, from e.g TE.
    3. Reimpl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
    [PCB - BOARD.brd, PCB - BOARD.sch]
2017-06-29 K-Line and L-Line optimization/improvements/changes
    1. Changed placement of the R33 and R34 resistors for K-LINE and L-LINE signal traces for future changes in J2 connector.
    2. T7 and T8 are now more separated than before.
    3. Because of above changes was needed to reroute signal traces for K-LINE and L-LINE signal traces.
    4. Changed width of the K-LINE signal trace going from T7 to R42 from 16mils to 12mils.
    5. Changed route for DLC power trace for SW-CAN transceiver.
    6. Added power plane for 3.3V on the top side of the board.
    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
    [PCB - BOARD.brd]
2017-07-08 BM71
    Reimplemented BM71 module.
    Module worked on 1st revision prototype board, but somehow it lost his MAC address after some configuration. This is known issue about this module and it will be changed in future.
    RN4871-V has the same pinout as BM71 and same recommended design, so it can be replaced without any problems.
    In future, board with USB and BT will be separate. For now,to lower the cost of prototype, such arrangement will stay for now.
    2. Maybe replace J2 connector with fancier one, from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
    [PCB - BOARD.brd, PCB - BOARD.sch]
2017-07-09 Optimization/fixes
    1, Fixed D2 and D3 LED's polarization.
    1. Elements near U2 IC pushed away to allow easier soldering.
    2. Added S1 switch instead of jumper for NVM reset.
    2. Added cut out for USB connector from daughter board.
    3. Because of cut-out D1, D2, D3, R1, R15, R16, S1 elements needed to be rearranged.
    4. Changed route of 3.3V power trace.
    5. Pushed away D4 and D5 elements to make a more space between them.
    6. Some other minor changes.
    ToDo:
    1. Pin description on the other side of the board.
    2. Logo
    3. Measurement points
    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
    [PCB - MODULE.brd, PCB - MODULE.sch]
2017-07-24 Minor things/Tweaks
    Main board:
    1. Deleted one front name on the top layer of the board.
    2. Added marking for 1st pin on the top of the board to easier recognize, where is front of the PCB.
    Daughter board:
    1. Adder missing 2 vias under 5V LDO. I deleted these two by mistake.
    2. Change position of the power status LED's
    3. Added description about which LED is for specific power line.
    4. Added marking for the 1st pin. He needs to be opposite of the marking on main board.
    [PCB - BOARD.brd, PCB - MODULE.brd]
2017-07-24 CleanUp
    1. Moved files to the separate folder.
    [PCB - BOARD.brd, PCB - BOARD.sch, PCB - MODULE.brd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]
2019-01-10 Revision 2 - USB
    First commit for revision 2 prototype, with USB communication. layout.
    Changes:
    1. TJA1048 changed for MCP2562 or TJ1051 (version with Vio pin)
    2. 3.3V LDO is now powered from 5V power source, instead of pure +12V
    3. Routing optimalization
    And others stuff
    [PCB - BOARD.brd, PCB - BOARD.sch, PCB - MODULE.brd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]

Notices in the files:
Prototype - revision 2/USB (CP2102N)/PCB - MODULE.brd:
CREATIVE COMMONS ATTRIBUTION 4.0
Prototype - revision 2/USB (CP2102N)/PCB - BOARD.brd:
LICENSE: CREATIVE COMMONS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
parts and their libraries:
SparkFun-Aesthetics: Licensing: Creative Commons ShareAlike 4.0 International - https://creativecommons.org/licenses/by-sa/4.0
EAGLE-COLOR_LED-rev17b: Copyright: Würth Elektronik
